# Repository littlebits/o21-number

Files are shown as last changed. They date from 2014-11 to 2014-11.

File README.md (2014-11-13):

Copyright 2014 littleBits Electronics.

littleBits, littleBits logo, Bits, cloudBit, are trademarks of littleBits Electronic Inc. 

littleBits Electronics, Inc. supports the Open Source Hardware Statement of Principles by making the circuit designs for its modules available pursuant to the CERN Hardware License, Version 1.2.

This is free software: you can redistribute it and/or modify it under the terms of the GNU General Public License as published by the Free Software Foundation, either version 3 of the License, or (at your option) any later version.

This software is distributed in the hope that it will be useful, but WITHOUT ANY WARRANTY; without even the implied warranty of MERCHANTABILITY or FITNESS FOR A PARTICULAR PURPOSE.  See the GNU General Public License at <http://www.gnu.org/licenses/> for more details.

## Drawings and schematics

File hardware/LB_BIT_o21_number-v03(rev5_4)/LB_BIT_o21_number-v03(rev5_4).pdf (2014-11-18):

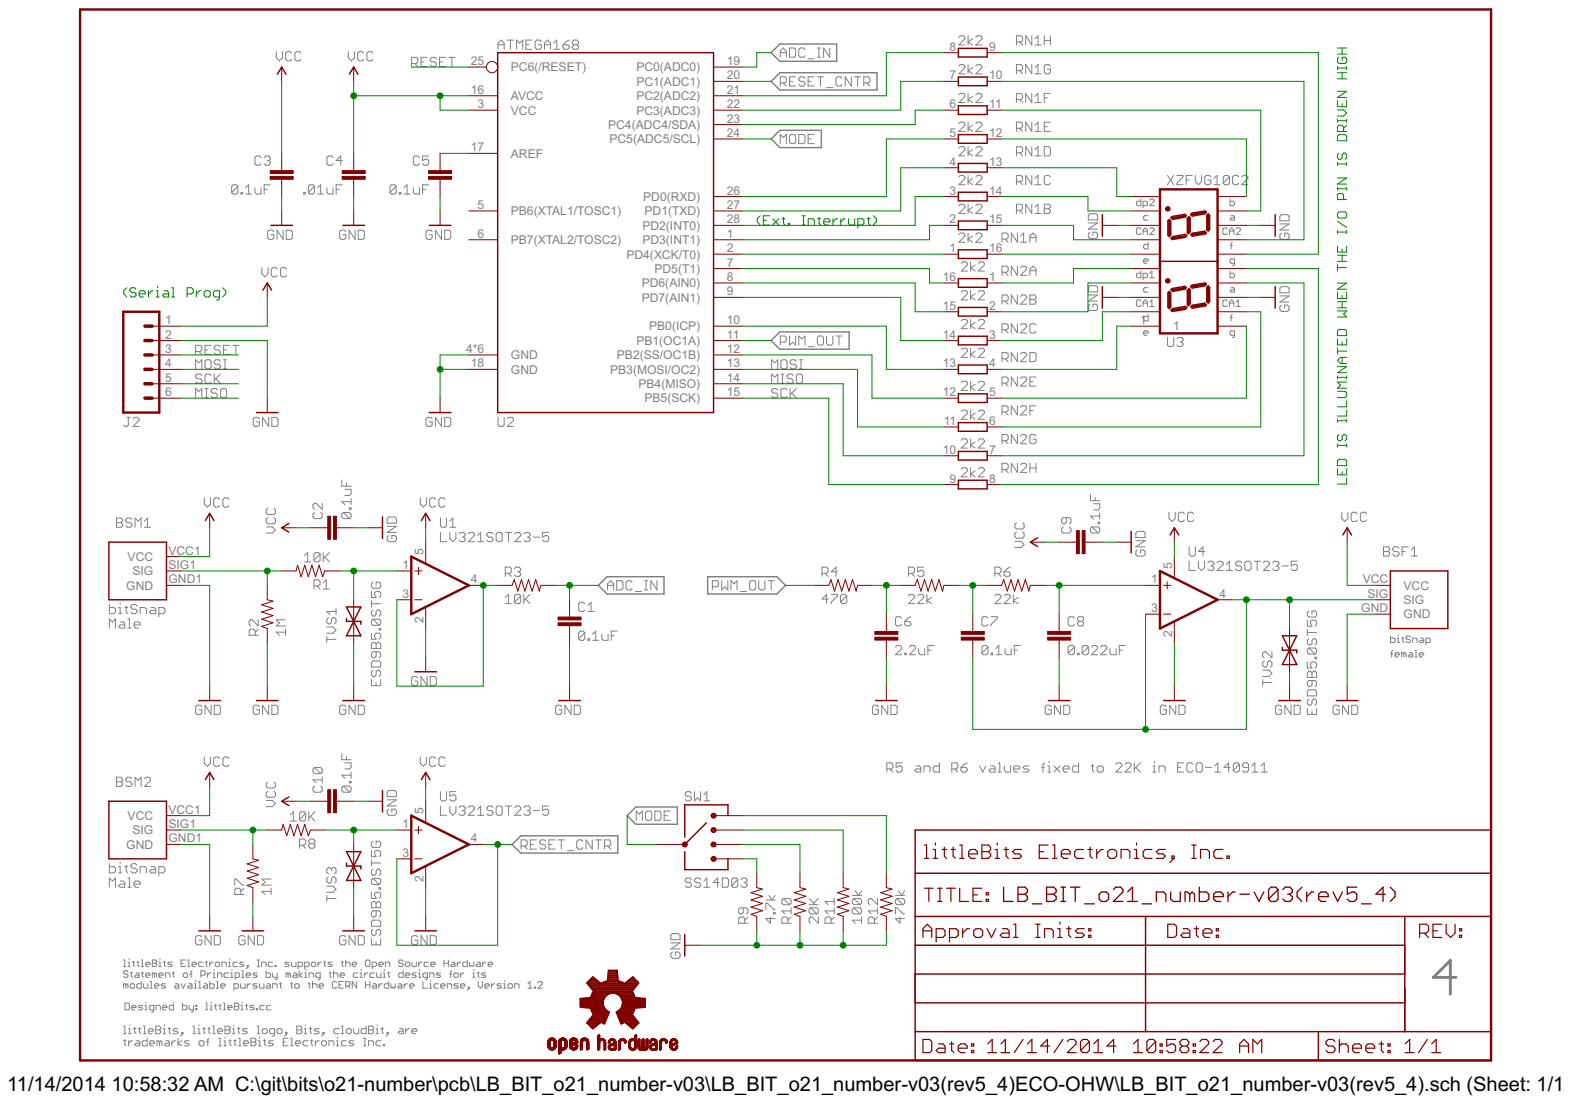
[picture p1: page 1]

11/14/2014 10:58:32 AM C:\git\bits\o21-number\pcb\LB_BIT_o21_number-v03\LB_BIT_o21_number-v03(rev5_4)ECO-OHW\LB_BIT_o21_number-v03(rev5_4).sch (Sheet: 1/1)

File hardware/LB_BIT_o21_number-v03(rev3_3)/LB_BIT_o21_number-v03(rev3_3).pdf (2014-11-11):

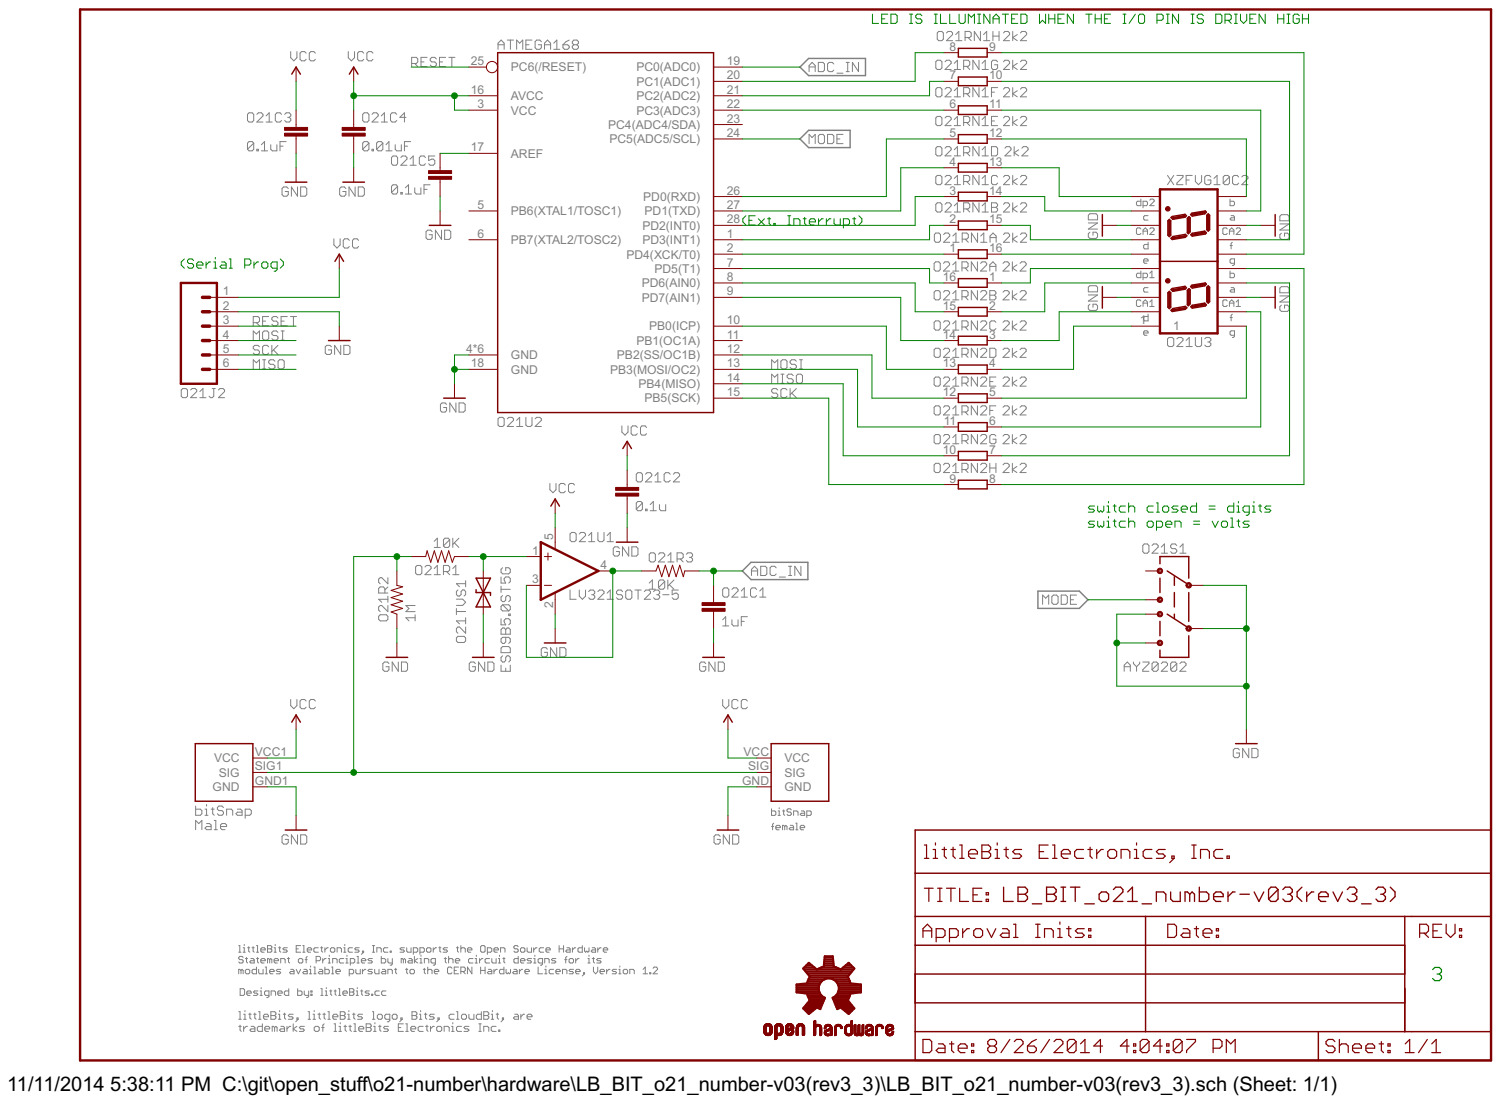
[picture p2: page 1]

11/11/2014 5:38:11 PM C:\git\open_stuff\o21-number\hardware\LB_BIT_o21_number-v03(rev3_3)\LB_BIT_o21_number-v03(rev3_3).sch (Sheet: 1/1)

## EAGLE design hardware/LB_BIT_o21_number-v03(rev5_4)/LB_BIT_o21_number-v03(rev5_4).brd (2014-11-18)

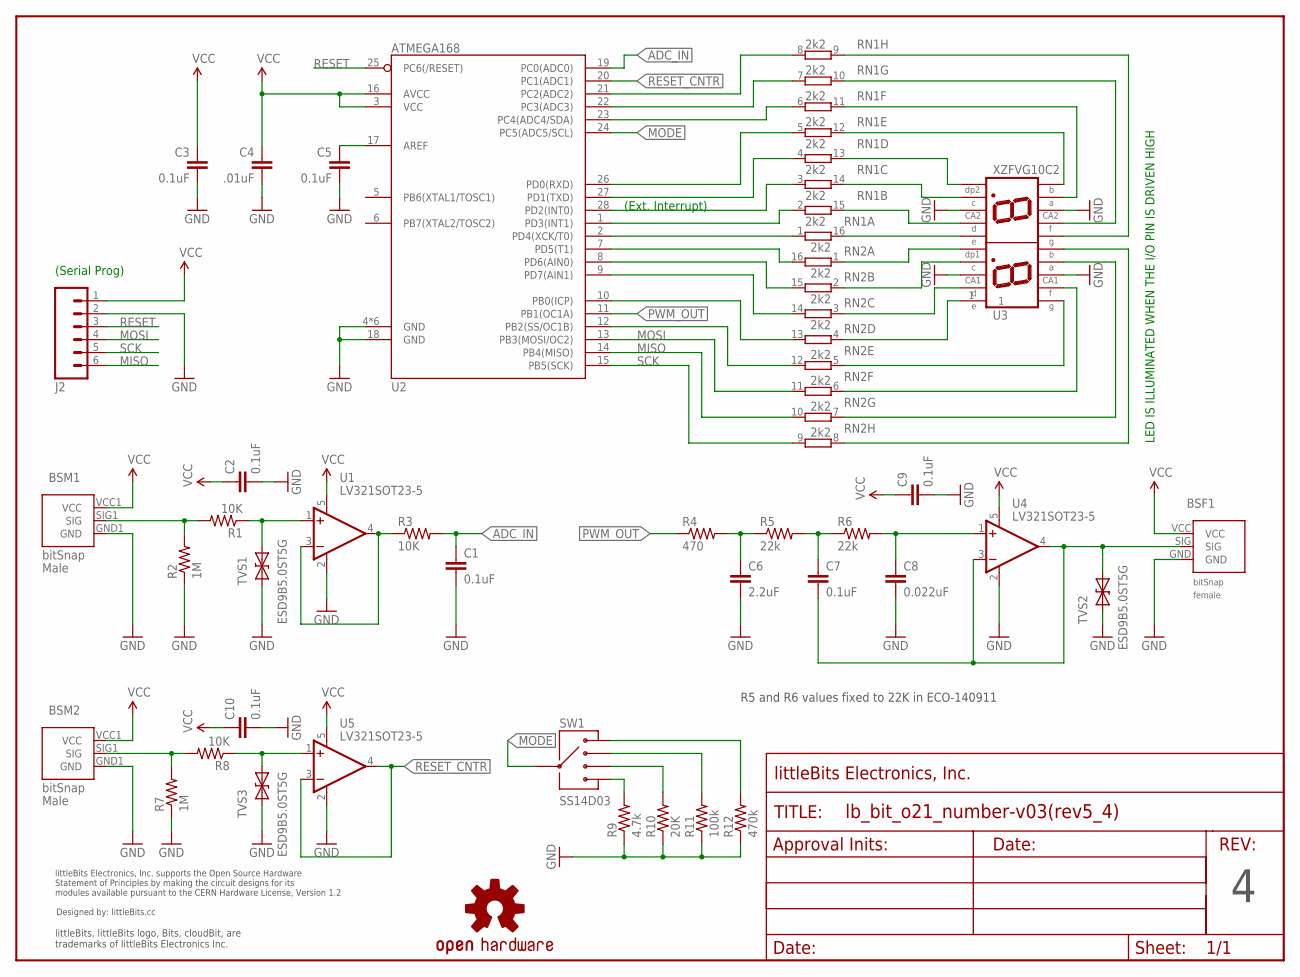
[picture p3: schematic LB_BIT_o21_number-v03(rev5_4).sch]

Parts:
BSF1: BITSNAP_V03_FEMALE
BSM1, BSM2: BITSNAP_V03_MALE
C1, C2, C3, C5, C7, C9, C10: 0.1uF; CAP-0603
C4: .01uF; CAP-0603
C6: 2.2uF; CAP-0603
C8: 0.022uF; CAP-0603
J2: HRD-60.1INCH_NO_SILKSCREEN; SIP6-SM-0.1IN-NOS.S.
R1, R3, R8: 10K; RES-0603
R2, R7: 1M; RES-0603
R4: 470; RES-0603
R5, R6: 22k; RES-0603
R9: 4.7k; RES-0603
R10: 20K; RES-0603
R11: 100k; RES-0603
R12: 470k; RES-0603
RN1, RN2: 2k2; EXB2HV
SW1: SS14D03; SWITCH-SLIDE-SP4T-SS14D03
TVS1, TVS2, TVS3: ESD9B5.0ST5G; SOD-923
U1, U4, U5: LV321SOT23-5; SOT23-5
U2: ATMEGA168; VQFN28
U3: XZFVG10C2; LED-DUAL7SEG-SM
U$1: FRAME-LETTER-OHWOHW; FABDWG01-OHW
U$2: OSHWCREDIT
U$27: OSHW-LOGOL; OSHW-LOGO-L

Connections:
ADC_IN: C1.1, R3.2, U2.19 (PC0(ADC0))
BIT_SIG: R3.1, U1.3 (-IN), U1.4 (OUT)
GND: BSF1.GND, BSM1.GND1 (GND), BSM2.GND1 (GND), C1.2, C2.2, C3.2, C4.2, C5.2, C6.2, C8.2, C9.2, C10.2, J2.2, R2.1, R7.1, R9.1, R10.1, R11.1, R12.1, TVS1.1 (A), TVS2.1 (A), TVS3.1 (A), U1.2 (V-), U2.4 (GND), U2.18 (GND), U2.TH (GND), U2.TH@1 (GND), U2.TH@2 (GND), U2.TH@3 (GND), U2.TH@4 (GND), U3.3, U3.8, U3.13, U3.18, U4.2 (V-), U5.2 (V-)
MISO: J2.6, RN2.10 (2), U2.14 (PB4(MISO))
MODE: SW1.COM, U2.24 (PC5(ADC5/SCL))
MOSI: J2.4, RN2.11 (2), U2.13 (PB3(MOSI/OC2))
unnamed: RN1.7 (1), U2.22 (PC3(ADC3))
unnamed: RN1.8 (1), U2.21 (PC2(ADC2))
unnamed: RN1.6 (1), U2.23 (PC4(ADC4/SDA))
unnamed: RN1.1, U2.2 (PD4(XCK/T0))
unnamed: RN1.2 (1), U2.1 (PD3(INT1))
unnamed: RN1.3 (1), U2.28 (PD2(INT0))
unnamed: RN1.4 (1), U2.27 (PD1(TXD))
unnamed: RN1.5 (1), U2.26 (PD0(RXD))
unnamed: RN2.16 (2), U2.7 (PD5(T1))
unnamed: RN2.15 (2), U2.8 (PD6(AIN0))
unnamed: RN2.14 (2), U2.9 (PD7(AIN1))
unnamed: RN2.13 (2), U2.10 (PB0(ICP))
unnamed: RN2.12 (2), U2.12 (PB2(SS/OC1B))
unnamed: C6.1, R4.2, R5.1
unnamed: C7.1, R5.2, R6.1
unnamed: RN1.16 (2), U3.6
unnamed: RN1.12 (2), U3.11
unnamed: RN1.11 (2), U3.12
unnamed: RN1.10 (2), U3.14
unnamed: RN1.9 (2), U3.15
unnamed: RN1.13 (2), U3.10
unnamed: RN1.15 (2), U3.7
unnamed: RN1.14 (2), U3.9
unnamed: C8.1, R6.2, U4.1 (+IN)
unnamed: RN2.1, U3.5
unnamed: RN2.2 (1), U3.4
unnamed: RN2.3 (1), U3.2
unnamed: RN2.4 (1), U3.1
unnamed: RN2.5 (1), U3.20
unnamed: RN2.6 (1), U3.19
unnamed: RN2.7 (1), U3.17
unnamed: RN2.8 (1), U3.16
unnamed: C5.1, U2.17 (AREF)
unnamed: R1.1, TVS1.2 (C), U1.1 (+IN)
unnamed: BSF1.SIG, C7.2, TVS2.2 (C), U4.3 (-IN), U4.4 (OUT)
unnamed: BSM2.SIG1 (SIG), R7.2, R8.2
unnamed: R12.2, SW1.1
unnamed: R8.1, TVS3.2 (C), U5.1 (+IN)
unnamed: R11.2, SW1.2
unnamed: R10.2, SW1.3
unnamed: R9.2, SW1.4
PWM_OUT: R4.1, U2.11 (PB1(OC1A))
RESET: J2.3, U2.25 (PC6(/RESET))
RESET_CNTR: U2.20 (PC1(ADC1)), U5.3 (-IN), U5.4 (OUT)
SCK: J2.5, RN2.9 (2), U2.15 (PB5(SCK))
SIG: BSM1.SIG1 (SIG), R1.2, R2.2
VCC: BSF1.VCC, BSM1.VCC1 (VCC), BSM2.VCC1 (VCC), C2.1, C3.1, C4.1, C9.1, C10.1, J2.1, U1.5 (V+), U2.3 (VCC), U2.16 (AVCC), U4.5 (V+), U5.5 (V+)

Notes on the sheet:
(Ext. Interrupt)
(Serial Prog)
LED IS ILLUMINATED WHEN THE I/O PIN IS DRIVEN HIGH
R5 and R6 values fixed to 22K in ECO-140911

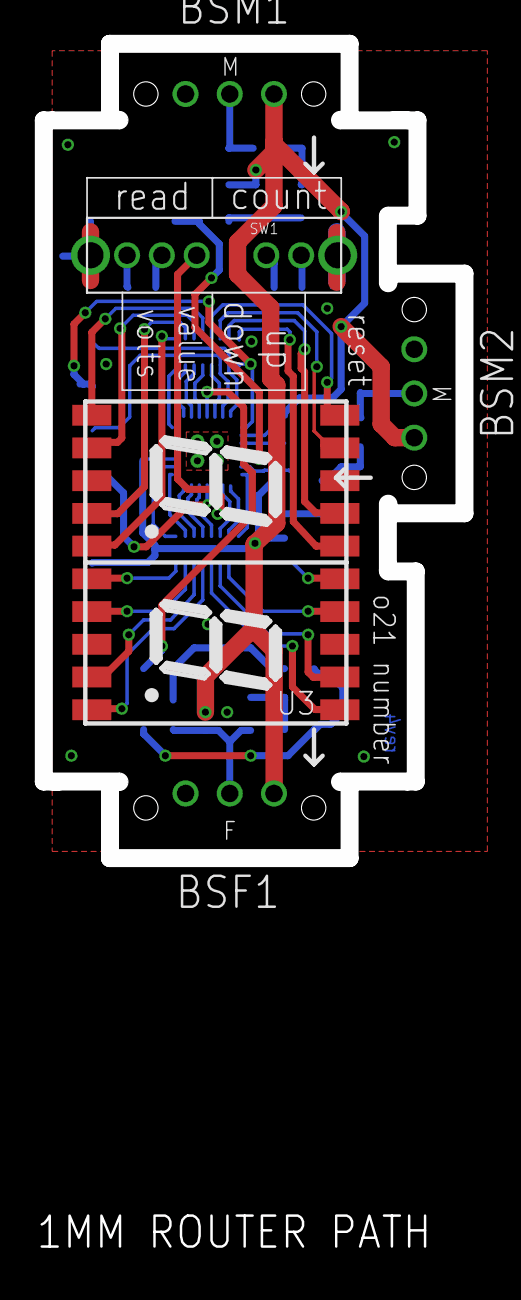
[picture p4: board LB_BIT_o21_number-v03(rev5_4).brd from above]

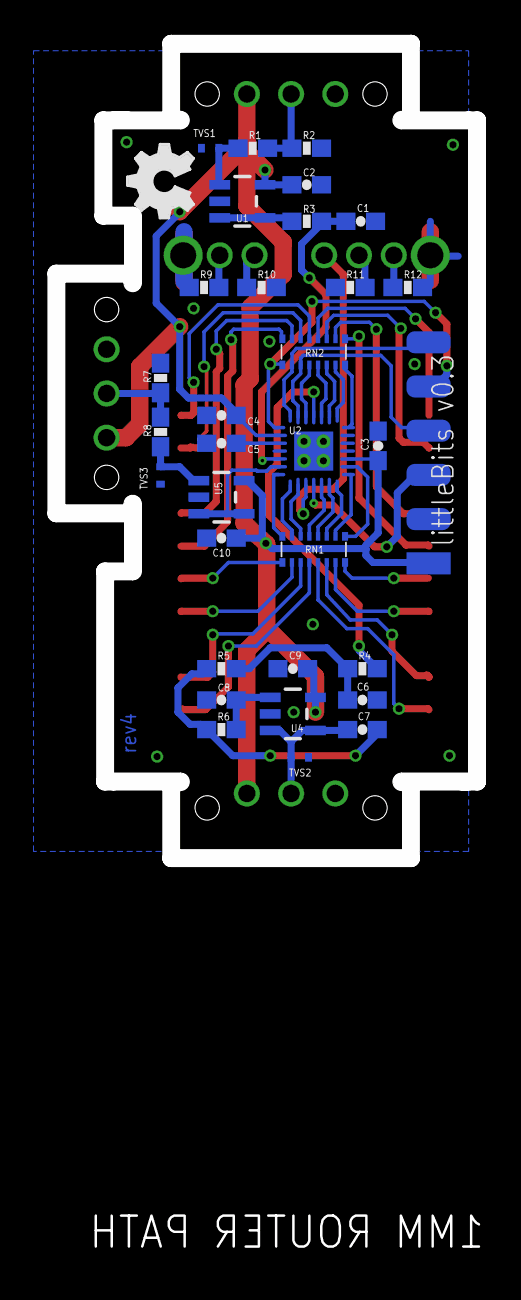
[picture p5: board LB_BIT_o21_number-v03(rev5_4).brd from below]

Board: 2 copper layers, 24.2 x 46.8 mm, 42 parts (32 on the bottom side), 53 nets.

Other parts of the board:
DRILEGEND: DRILEGEND
U$20: OSHW_FILLX150_NOTEXT

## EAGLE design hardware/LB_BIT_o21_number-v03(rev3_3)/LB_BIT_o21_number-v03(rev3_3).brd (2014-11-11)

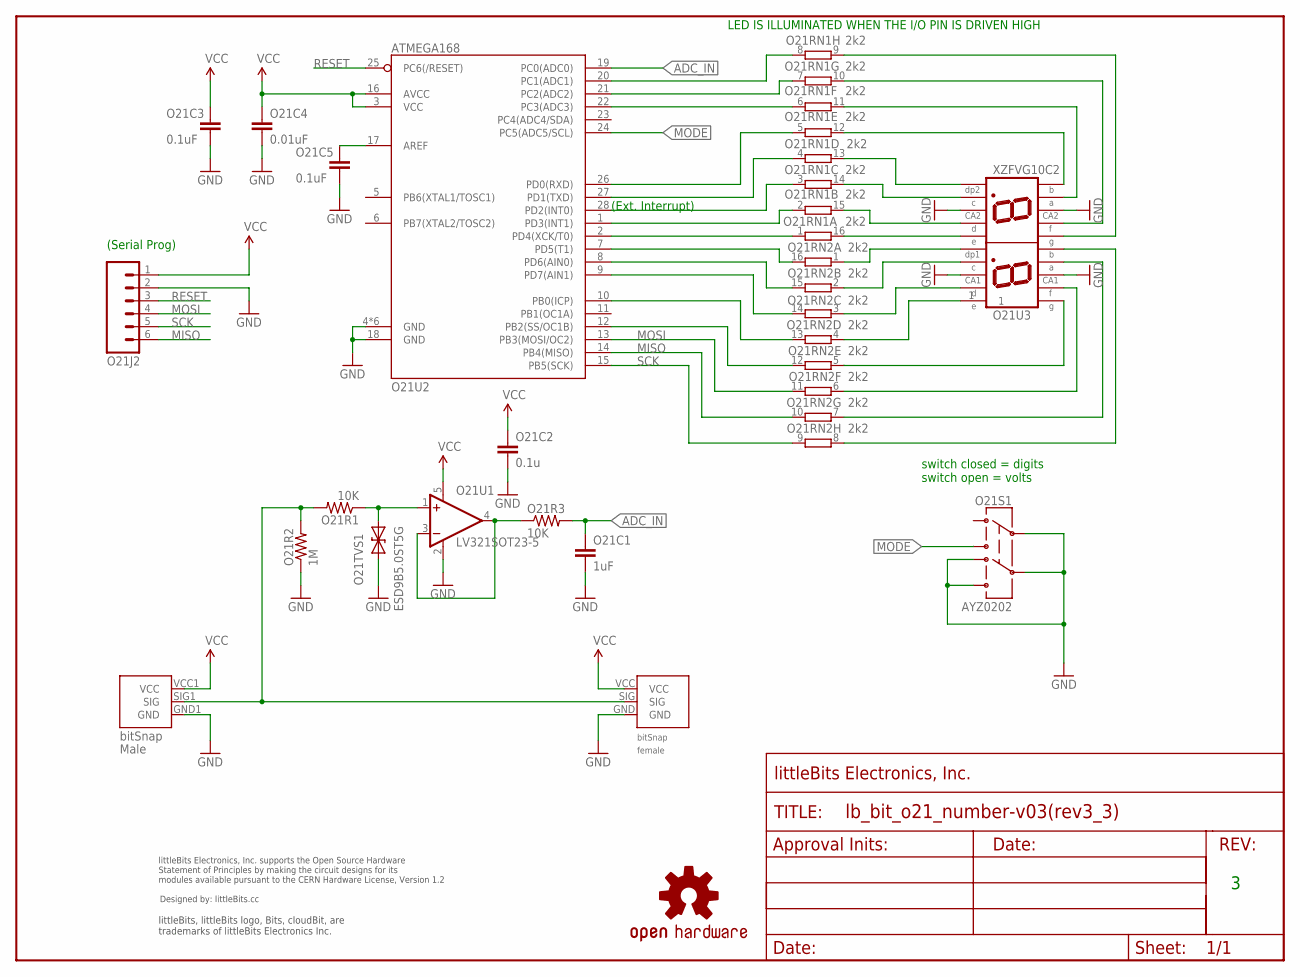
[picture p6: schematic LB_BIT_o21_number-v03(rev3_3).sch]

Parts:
O21BSF1: BITSNAP_V03_FEMALE
O21BSM1: BITSNAP_V03_MALE
O21C1: 1uF; CAP-0603
O21C2: 0.1u; CAP-0603
O21C3, O21C5: 0.1uF; CAP-0603
O21C4: 0.01uF; CAP-0603
O21J2: HRD-60.1INCH_NO_SILKSCREEN; SIP6-SM-0.1IN-NOS.S.
O21R1, O21R3: 10K; RES-0603
O21R2: 1M; RES-0603
O21RN1, O21RN2: 2k2; EXB2HV
O21S1: AYZ0202
O21TVS1: ESD9B5.0ST5G; SOD-923
O21U1: LV321SOT23-5; SOT23-5
O21U2: ATMEGA168; VQFN28
O21U3: XZFVG10C2; LED-DUAL7SEG-SM
U$7: OSHWCREDIT
U$16: FRAME-LETTER-OHWOHW; FABDWG01-OHW
U$27: OSHW-LOGOL; OSHW-LOGO-L

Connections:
ADC_IN: O21C1.1, O21R3.2, O21U2.19 (PC0(ADC0))
BIT_SIG: O21R3.1, O21U1.3 (-IN), O21U1.4 (OUT)
GND: O21BSF1.GND, O21BSM1.GND1 (GND), O21C1.2, O21C2.2, O21C3.2, O21C4.2, O21C5.2, O21J2.2, O21R2.1, O21S1.2, O21S1.4, O21S1.5, O21S1.6, O21TVS1.1 (A), O21U1.2 (V-), O21U2.4 (GND), O21U2.18 (GND), O21U2.TH (GND), O21U2.TH@1 (GND), O21U2.TH@2 (GND), O21U2.TH@3 (GND), O21U2.TH@4 (GND), O21U3.3, O21U3.8, O21U3.13, O21U3.18
MISO: O21J2.6, O21RN2.10 (2), O21U2.14 (PB4(MISO))
MODE: O21S1.3, O21U2.24 (PC5(ADC5/SCL))
MOSI: O21J2.4, O21RN2.11 (2), O21U2.13 (PB3(MOSI/OC2))
unnamed: O21RN1.7 (1), O21U2.21 (PC2(ADC2))
unnamed: O21RN1.8 (1), O21U2.20 (PC1(ADC1))
unnamed: O21RN1.6 (1), O21U2.22 (PC3(ADC3))
unnamed: O21RN1.1, O21U2.2 (PD4(XCK/T0))
unnamed: O21RN1.2 (1), O21U2.1 (PD3(INT1))
unnamed: O21RN1.3 (1), O21U2.28 (PD2(INT0))
unnamed: O21RN1.4 (1), O21U2.27 (PD1(TXD))
unnamed: O21RN1.5 (1), O21U2.26 (PD0(RXD))
unnamed: O21RN2.16 (2), O21U2.7 (PD5(T1))
unnamed: O21RN2.15 (2), O21U2.8 (PD6(AIN0))
unnamed: O21RN2.14 (2), O21U2.9 (PD7(AIN1))
unnamed: O21RN2.13 (2), O21U2.10 (PB0(ICP))
unnamed: O21RN2.12 (2), O21U2.12 (PB2(SS/OC1B))
unnamed: O21RN1.16 (2), O21U3.6
unnamed: O21RN1.12 (2), O21U3.11
unnamed: O21RN1.11 (2), O21U3.12
unnamed: O21RN1.10 (2), O21U3.14
unnamed: O21RN1.9 (2), O21U3.15
unnamed: O21RN1.13 (2), O21U3.10
unnamed: O21RN1.15 (2), O21U3.7
unnamed: O21RN1.14 (2), O21U3.9
unnamed: O21RN2.1, O21U3.5
unnamed: O21RN2.2 (1), O21U3.4
unnamed: O21RN2.3 (1), O21U3.2
unnamed: O21RN2.4 (1), O21U3.1
unnamed: O21RN2.5 (1), O21U3.20
unnamed: O21RN2.6 (1), O21U3.19
unnamed: O21RN2.7 (1), O21U3.17
unnamed: O21RN2.8 (1), O21U3.16
unnamed: O21C5.1, O21U2.17 (AREF)
unnamed: O21R1.1, O21TVS1.2 (C), O21U1.1 (+IN)
RESET: O21J2.3, O21U2.25 (PC6(/RESET))
SCK: O21J2.5, O21RN2.9 (2), O21U2.15 (PB5(SCK))
SIG: O21BSF1.SIG, O21BSM1.SIG1 (SIG), O21R1.2, O21R2.2
VCC: O21BSF1.VCC, O21BSM1.VCC1 (VCC), O21C2.1, O21C3.1, O21C4.1, O21J2.1, O21U1.5 (V+), O21U2.3 (VCC), O21U2.16 (AVCC)

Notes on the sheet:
(Ext. Interrupt)
(Serial Prog)
LED IS ILLUMINATED WHEN THE I/O PIN IS DRIVEN HIGH
switch closed = digits switch open = volts

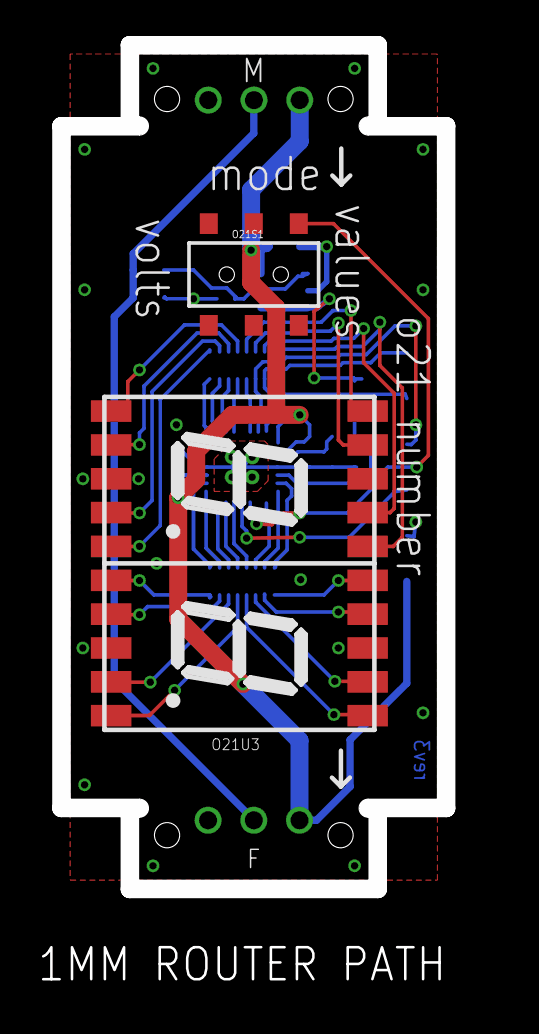
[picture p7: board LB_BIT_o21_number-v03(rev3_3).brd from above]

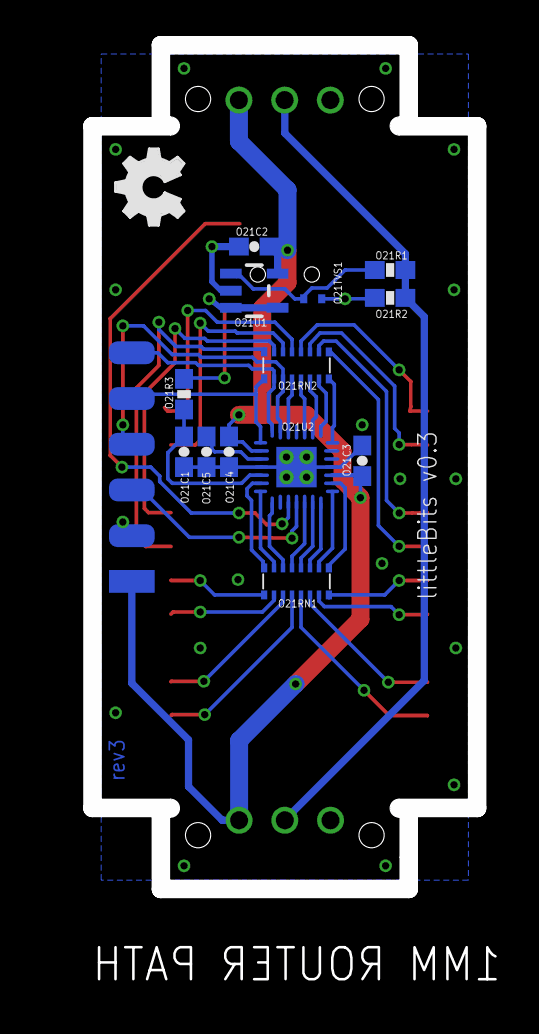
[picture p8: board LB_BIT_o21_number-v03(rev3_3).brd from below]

Board: 2 copper layers, 21.4 x 46.9 mm, 22 parts (14 on the bottom side), 41 nets.

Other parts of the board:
U$20: OSHW_FILLX150_NOTEXT

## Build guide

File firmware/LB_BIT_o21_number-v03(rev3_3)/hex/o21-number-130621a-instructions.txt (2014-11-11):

Programming Instructions

Step 1) Flash the micro controller with the accompanying .hex file.

Step 2) Set the fuses on the micro controller. Use the following fuse settings:

		EXTENDED:	0xF9
		HIGH:		0xCD
		LOW:		0x62

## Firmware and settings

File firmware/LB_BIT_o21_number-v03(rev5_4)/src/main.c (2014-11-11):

/*
*	main.c
*	uC = ATMega168-PA
*	SysClk = 1MHz (originating from internal 8 MHz RC oscillator and 1/8 prescalar)
*	Created: 5/27/2014 11:11:43 AM
*	Authors: littleBits Electronics, Inc.
*			MJ, Rory, Kristin
*
* Copyright 2014 littleBits Electronics
*
* This file is part of o21-number.
*
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
* This file incorporates work covered by the following copyright and
* permission notice:
*
*	Copyright 2013
*	source: http://www.dsprelated.com/showcode/304.php
*	
*	The code is released under Creative Commons Attribution 3.0. See the license
* 	at <https://creativecommons.org/licenses/by/3.0/us/legalcode> for more details.
*/


#include "o21-number.h"
#include "led_display.h"
#include "pwm_lookup.h"


// FUNCTION PROTOTYPES
static inline int16_t dsp_ema_i16(int16_t in, int16_t average, uint8_t alpha);	// First-order IIR LPF on incoming ADC signal
static inline void calc_number(struct display_data *display_values);			// Compute the outgoing display data in VALUES mode
static inline void calc_voltage(struct display_data *display_values);			// Compute the outgoing display data in VOLTS mode
static inline void output_display(struct display_data *display_values);			// Send the computed data out to the LED SSD for VALUES or VOLTS modes
static inline void output_display_counter(uint8_t value);						// Send the computed data out to the LED SSD for UP or DOWN modes

void reset_counter(uint8_t);		// Reset the counter value in UP or DOWN modes to the default values
void initialize_display();			// Initialize the LED SSD in UP or DOWN modes
void setup();						// Initialize WDT, LED SSD, pins, and interrupts


int main(void)
{

	setup();		// Initialize everything

	while(1)
	{
				
		// DSP for incoming ADC samples
		// We're using a 1-pole anti-aliasing LPF where Fc = 16 Hz
		//if( (state = !ready_for_adc_sample) )
		if (!ready_for_adc_sample)
		{
			sample_out_int16 = dsp_ema_i16(sample_in_int16, sample_out_int16, DSP_EMA_I16_ALPHA(0.01));		// LPF with 1st order exponential moving average IIR filter
			ready_for_adc_sample = 1;					// Set this flag HIGH again so that the ADC can take in a new sample in its next ISR
		}
		
		// The following 3 operations will execute one at a time at a rate of 333 Hz (rate depends on timer2's ISR)
		if (!operation_complete)
		{
			switch(state)
			{
				// case: READ MODE SWITCH
				case 0:
				
				if (mode_in <= 300)
				{
					switch_mode = UP;
					update_pwm = 1;
				}
				else if (mode_in > 300 && mode_in <= 600){
					switch_mode = DOWN;
					update_pwm = 1;
				}
				else if (mode_in > 600 && mode_in <= 850)
				{
					switch_mode = VALUES;
				}
				else if(mode_in > 850 && mode_in <= 1023)
				{
					switch_mode = VOLTS;
				}
				
				break;
				
				// case: COMPUTE DATA IN VALUES AND VOLTS MODES
				case 1:
				filtered_sample = (sample_out_int16 + 0x8000) >> 8;			// get filtered sample, offset to 0-65535 range, and downscale to 8-bit range
				if (switch_mode == VALUES)
				{
					calc_number(&new_output);								// compute date for SSD
				}
				else if (switch_mode == VOLTS)
				{
					calc_voltage(&new_output);								// compute data for SSD
				}

				break;
				

				// case: OUTPUT DATA TO DISPLAY
				case 2:
				
				if(switch_mode == VALUES || switch_mode == VOLTS)
				{
					output_display(&new_output);						// output to SSD
				}
				else if (switch_mode == UP || switch_mode == DOWN)
				{
					output_display_counter(counter_value);				// output to SSD
				}
				
				break;
				

			} //end switch
			
			operation_complete = 1;			// Set this flag HIGH so that timer2's ISR will know to move us into next state
			
			
		} //end if op complete
		
		
		// On rising edge of reset bitsnap pin, reset the counter to default values
		reset_state = READ_RESET_BUTTON();
		if(reset_state && !last_reset_state)
		reset_counter(switch_mode);
		last_reset_state = reset_state;
		
		wdt_reset();
		
	} //end while
	
} //end main


void setup()
{
	MCUSR &= ~(WDRF << 1);				// Clear the watchdog system reset flag
	wdt_enable(WDTO_60MS);				// Enable the watchdog timer. We specify a max-out period of 60 mS
	wdt_reset();						// Reset the watchdog timer

	adc_init(8);						// Initialize ADC. Use clock frequency of 1/8 of sysclock (125kHz). ADC reading takes 13 cycles, so ADC sample rate is 9.615kHz.
	_delay_ms(10);

	init_pwm_1();						// initialize PWM output and timer 1
	init_timer2();						// Initialize timer 2 to cycle through 3 states
	
	ENABLE_PCINT1();					// Enable the PCINT1
	INIT_PCINT1();						// Initialize PCINT1 trigger on PC0
	
	INIT_SWITCH();						// Initialize the mode switch pin
	INIT_RESET_BUTTON();				// Initialize the reset bitsnap signal pin
	INIT_INPUT_PULSE();					// Initialize the input bitsnap signal pin
	_delay_ms(1);
	
	init_led_outputs();					// Initialize 7 segment display
	initialize_display();				// Initialize display for counter mode

	wdt_reset();						// Reset WDT
}



ISR(PCINT1_vect)
{
	
	// On rising edge on input bitsnap pin, increment or decrement counter value and update pwm for output bitsnap
	// If there is a pulse on the input bitsnap
	if(READ_INPUT_PULSE())
	{
		switch(switch_mode)
		{
			case UP:
			// if we haven't hit our lower boundary
			if(counter_value < DOWN_DEFAULT)
			{
				counter_value++;	// increment
				update_pwm = 1;		// set flag to update PWM output
			}
			break;
			
			case DOWN:
			// if we haven't hit our upper boundary
			if(counter_value > UP_DEFAULT)
			{
				counter_value--;	// decrement
				update_pwm = 1;		// set flag to update PWM output
			}
			break;
			
			default:
			break;
			
		}
		
	}

	
}

// Interrupt should fire at a rate of ~1kHz
ISR(TIMER1_COMPA_vect)
{
	if (switch_mode == VALUES || switch_mode == VOLTS)
	{
		OUTPUT_BITSNAP = sig_in;
	}
	else if (switch_mode == UP || switch_mode == DOWN)
	{
		if(update_pwm)
		{
			OUTPUT_BITSNAP = pwm_lookup[counter_value];	//set output bitsnap pin to the scaled PWM output
			update_pwm = 0;								// clear the flag to update the PWM output
		}
	}

	
}


// Interrupt should fire at a rate of ~1kHz
ISR (TIMER2_COMPA_vect)
{
	mode_in = adc_read(5);			// read adc from switch mode pin

	if(operation_complete)
	{
		state++;
		state = state%3;
		operation_complete = 0;
	}
}


// This interrupt routine will be called every time that the ADC executes a new reading.
ISR(ADC_vect)
{
	
	if (switch_mode == VALUES || switch_mode == VOLTS)
	{
		// if we're ready to take in another ADC sample
		if(ready_for_adc_sample)
		{
			sig_in = adc_read(0);						// read adc on input bitsnap pin
			sample_in_int16 = (sig_in - 0x200) << 6;	// move reading to range of -512 to 512, upscale into 16-bit range
			ready_for_adc_sample = 0;					// clear flag so DSP can happen
		}
	}

}



// This is my modified version of original source code from: http://www.dsprelated.com/showcode/304.php
// This is a first order IIR lowpass filter, called an Exponential Moving Average filter.
// Decreasing the value of alpha lowers the cutoff frequency of the filter
int16_t dsp_ema_i16(int16_t in, int16_t average, uint8_t alpha)
{
	int32_t tmp0; // calcs must be done in 32-bit math to avoid overflow
	tmp0 = (int32_t)in * (alpha) + (int64_t)average * (256 - alpha);
	return (int16_t)((tmp0 + 128) / 256); // scale back to 32-bit (with rounding)
}

// Output all of the calculated values to the seven segment LED display:
static inline void output_display(struct display_data *display_values)
{
	
	display_left[display_values->left_digit]();
	display_right[display_values->right_digit]();
	display_decimal(display_values->decimal_point);
}

// Output counter mode values to LED SSD display:
static inline void output_display_counter(uint8_t value)
{
	uint8_t tens = value / 10;		// determine the most significant digit
	uint8_t ones = value % 10;		// determine the least significant digit
	
	display_left[tens]();			// put the MSD on the display
	display_right[ones]();			// put the LSD on the display
}


static inline void calc_number(struct display_data *display_values)
{
	
	if(filtered_sample > 249)
	filtered_sample = 249;
	
	// First let's calculate the 10's digit:
	// At this point the signal now ranges from 0-255.
	// We divide this into 10 sections (each with a difference of 26)
	// So tens_val will range from 0 to 9:
	uint16_t temp_left = filtered_sample/25;
	
	// Put this in here as a safety-guard to be sure we never try to access an address space beyond the limits of arrays
	if(temp_left > 9)
	temp_left = 9;
	
	// And finally pass these values on to our struct that holds data to be displayed:
	display_values->left_digit = temp_left;
	
	// Now to calculate the ones digit:
	// First we remove the largest multiple of 25 from the variable.
	// After this operation, remainder will range from 0 to 24:
	// We would want to divide 24 by 2.4 to get 10 divisions, but instead we shift both those operands up 8 bits:
	// So (24/10) << 8 = 6144/10 = 614... Divide by this value to get results ranging from 0-9...
	// This is fixed point arithmetic to avoid floating point computations
	
	uint16_t remainder = (filtered_sample%25) << 8;
	uint8_t ones_val = remainder/614;
	
	// Set any excessively high values to 9 (this operation will introduce a slight yet negligible inaccuracy to our display)
	if(ones_val > 9)
	ones_val = 9;
	
	// Pass on the computed ones value
	display_values->right_digit = ones_val;
	
	// Finally, make sure that the decimal point is turned off
	display_values->decimal_point = OFF;
	
}


// Recall for voltage mode, a shift of 5 bits (out of 256) in ADC readings corresponds to a change of 0.1 V (which should cause a display change)
static inline void calc_voltage(struct display_data *display_values)
{
	// Set up this new variable to hold our adc readings for these calculations
	// Apply an offset of two bits just for accuracy...
	// uint16_t temp_adc = filtered_sample + 1;
	
	uint16_t temp_adc = filtered_sample + 2;
	
	// At this point the signal now ranges from 0-255.
	// First let's calculate the 1's digit in voltage:
	// We divide the adc reading (ranging from 0-255) by 51.
	// After this operation, ones_digit will range from 0 to 5.
	uint8_t ones_digit = temp_adc/51;
	
	// If the value rises above 5, then cap it
	if (ones_digit > 5)
	ones_digit = 5;
	
	// Pass this computed value back out of the function to our struct that holds data to be displayed
	display_values->left_digit = ones_digit;
	
	// Now to calculate the decimal digit:
	// First we remove the largest multiple of 51 from the variable.
	// After this operation, remainder will vary from 0 to 50:
	uint8_t remainder = temp_adc%51;
	
	// This is a small scale-up patch used because our displays were outputting inaccurately high values in the 4V region.
	if( (ones_digit == 4) && (remainder > 4) )
	remainder -= 2;

	
	// This is a small scale-up patch used because our readings were outputting inaccurately low values in the lower half of the 1 - 1.5V region.
	//if( (ones_digit == 1) && ( remainder < 25) )
	//remainder += 2;
	
	// Now we divide this value by 5.
	// After this operation, dec_digit will range from 0 to 10
	uint8_t dec_digit = remainder/5;
	
	// Reduce any values of 10 to 9 (this operation will introduce a slight yet negligible inaccuracy to our display)
	if( dec_digit > 9)
	dec_digit = 9;
	
	// Now pass this computed value out of the function
	display_values->right_digit = dec_digit;

	display_values->decimal_point = ON;
}


void reset_counter(uint8_t sw_state)
{
	// if the bit is set to UP mode
	if(sw_state == UP)
	counter_value = UP_DEFAULT;
	// else the bit is set to DOWN mode
	else if (sw_state == DOWN)
	counter_value = DOWN_DEFAULT;
	
	update_pwm = 1;		// set the flag to update the PWM output
}

void initialize_display()
{
	mode_in = adc_read(5);		// read adc input from switch
	
	if (mode_in < 300)
	{
		switch_mode = UP;
		reset_counter(switch_mode);
		output_display_counter(counter_value);
	}
	else if (mode_in > 300 && mode_in < 600){
		switch_mode = DOWN;
		reset_counter(switch_mode);
		output_display_counter(counter_value);
	}
	else if(mode_in > 600 && mode_in < 850)
	{
		switch_mode = VALUES;
	}
	else if(mode_in > 850 && mode_in <1023)
	{
		switch_mode = VOLTS;
	}

}

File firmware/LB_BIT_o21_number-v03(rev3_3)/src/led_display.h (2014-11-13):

/*
 * led_display.h\
 *
 * Created: 5/22/2014 5:18:23 PM
 *
 * Copyright 2014 littleBits Electronics
 *
 * This file is part of o21-number.
 *
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
 * This file incorporates work covered by the following copyright and
 * permission notice:
 *
 *	Copyright 2013
 *	source: http://www.dsprelated.com/showcode/304.php
 *	
 *	The code is released under Creative Commons Attribution 3.0. See the license
 * 	at <https://creativecommons.org/licenses/by/3.0/us/legalcode> for more details.
 */ 


#ifndef LED_DISPLAY_H_
#define LED_DISPLAY_H_

#define LEFT_A (1 << PB4)
#define LEFT_B (1 << PB5)
#define LEFT_C (1 << PD6)
#define LEFT_D (1 << PD7)
#define LEFT_E (1 << PB0)
#define LEFT_F (1 << PB3)
#define LEFT_G (1 << PB2)

#define RIGHT_A (1 << PC4)
#define RIGHT_B (1 << PD0)
#define RIGHT_C (1 << PD2)
#define RIGHT_D (1 << PD3)
#define RIGHT_E (1 << PD4)
#define RIGHT_F (1 << PC3)
#define RIGHT_G (1 << PC2)

#define DECIMAL_PT_L (1 << PD5)
#define DECIMAL_PT_R (1 << PD1)


// This enumeration will be used in the display_decimal() function below:
enum decimal_point {OFF, ON};

// This function will control the pin that drives the decimal point of the LED display
inline void display_decimal(int decimal_status)
{
	if(decimal_status == ON)
	PORTD |= DECIMAL_PT_L;			// Turn the LED display for decimal point on
	else 						// else assume decimal_status == OFF, so:
	PORTD &= ~DECIMAL_PT_L;			// Turn the LED display for decimal point off
}

// This function specifies the behavior of the pins that drive the LED display.
// Setting a '1' in these ports designates the pins as outputs (as opposed to inputs or something else)

inline void init_led_outputs()
{
	DDRB |= LEFT_A|LEFT_B|LEFT_E|LEFT_F|LEFT_G;
	DDRC |= RIGHT_A|RIGHT_F|RIGHT_G;
	DDRD |= LEFT_C|LEFT_D|RIGHT_B|RIGHT_C|RIGHT_D|RIGHT_E|DECIMAL_PT_L|DECIMAL_PT_R;
}

///////////////////////////////////////////////////////////////////////////////////////////////////////////////////////////
///////////////////// The following functions control the pins that drive the LED display's left digit ////////////////////
///////////////////////////////////////////////////////////////////////////////////////////////////////////////////////////


void l_zero()
{
	PORTB |= LEFT_A|LEFT_B|LEFT_E|LEFT_F;
	PORTB &= ~LEFT_G;
	
	PORTD |= LEFT_C|LEFT_D;
}

void l_one()
{
	PORTB |= LEFT_B;
	PORTB &= ~(LEFT_A|LEFT_E|LEFT_F|LEFT_G);

	PORTD |= LEFT_C;
	PORTD &= ~LEFT_D;
}

void l_two()
{
	PORTB |= LEFT_A|LEFT_B|LEFT_E|LEFT_G;
	PORTB &= ~LEFT_F;

	PORTD |= LEFT_D;
	PORTD &= ~LEFT_C;
}

void l_three()
{
	PORTB |= LEFT_A|LEFT_B|LEFT_G;
	PORTB &= ~(LEFT_F|LEFT_E);

	PORTD |= LEFT_C|LEFT_D;
}

void l_four()
{
	PORTB |= LEFT_F|LEFT_B|LEFT_G;
	PORTB &= ~(LEFT_A|LEFT_E);

	PORTD |= LEFT_C;
	PORTD &= ~LEFT_D;
}

void l_five()
{
	PORTB |= LEFT_A|LEFT_F|LEFT_G;
	PORTB &= ~(LEFT_B|LEFT_E);

	PORTD |= LEFT_C|LEFT_D;
}

void l_six()
{
	PORTB |= LEFT_A|LEFT_E|LEFT_F|LEFT_G;
	PORTB &= ~LEFT_B;

	PORTD |= LEFT_C|LEFT_D;
}

void l_seven()
{
	PORTB |= LEFT_A|LEFT_B;
	PORTB &= ~(LEFT_E|LEFT_F|LEFT_G);

	PORTD |= LEFT_C;
	PORTD &= ~LEFT_D;
}

void l_eight()
{
	PORTB |= LEFT_A|LEFT_B|LEFT_E|LEFT_F|LEFT_G;

	PORTD |= LEFT_C|LEFT_D;
}

void l_nine()
{
	PORTB |= LEFT_A|LEFT_B|LEFT_E|LEFT_F|LEFT_G;
	PORTB &= ~LEFT_E;

	PORTD |= LEFT_C|LEFT_D;
}




////////////////////////////////////////////////////////////////////////////////////////////////////////////////////////////
///////////////////// The following functions control the pins that drive the LED display's right digit ////////////////////
////////////////////////////////////////////////////////////////////////////////////////////////////////////////////////////

void r_zero()
{
	PORTC |= RIGHT_A|RIGHT_F;
	PORTC &= ~RIGHT_G;

	PORTD |= RIGHT_B|RIGHT_C|RIGHT_D|RIGHT_E;
}

void r_one()
{
	PORTC &= ~(RIGHT_A|RIGHT_F|RIGHT_G);

	PORTD |= RIGHT_B|RIGHT_C;
	PORTD &= ~(RIGHT_D|RIGHT_E);
}

void r_two()
{
	PORTC |= RIGHT_A|RIGHT_G;
	PORTC &= ~RIGHT_F;

	PORTD |= RIGHT_B|RIGHT_D|RIGHT_E;
	PORTD &= ~RIGHT_C;
}

void r_three()
{
	PORTC |= RIGHT_A|RIGHT_G;
	PORTC &= ~RIGHT_F;

	PORTD |= RIGHT_B|RIGHT_D|RIGHT_C;
	PORTD &= ~RIGHT_E;
}

void r_four()
{
	PORTC |= RIGHT_G|RIGHT_F;
	PORTC &= ~RIGHT_A;

	PORTD |= RIGHT_B|RIGHT_C;
	PORTD &= ~(RIGHT_E|RIGHT_D);
}

void r_five()
{
	PORTC |= RIGHT_A|RIGHT_F|RIGHT_G;

	PORTD |= RIGHT_D|RIGHT_C;
	PORTD &= ~(RIGHT_B|RIGHT_E);
}

void r_six()
{
	PORTC |= RIGHT_A|RIGHT_F|RIGHT_G;

	PORTD |= RIGHT_C|RIGHT_D|RIGHT_E;
	PORTD &= ~RIGHT_B;
}

void r_seven()
{
	PORTC &= ~(RIGHT_F|RIGHT_G);
	PORTC |= RIGHT_A;

	PORTD |= RIGHT_C|RIGHT_B;
	PORTD &= ~(RIGHT_D|RIGHT_E);
}

void r_eight()
{
	PORTC |= RIGHT_A|RIGHT_F|RIGHT_G;

	PORTD |= RIGHT_B|RIGHT_C|RIGHT_D|RIGHT_E;
}

void r_nine()
{
	PORTC |= RIGHT_A|RIGHT_F|RIGHT_G;

	PORTD |= RIGHT_B|RIGHT_C|RIGHT_D;
	PORTD &= ~RIGHT_E;
}


///////////////////////////////////////////////////////////////////////////////////////////////////////////////////////////
///	These are arrays of pointers to functions. These arrays function like lookup tables for the left and			///
/// 	right display numbers. The functions that we point to control the GPIO pins that drive the LED displays		///
///////////////////////////////////////////////////////////////////////////////////////////////////////////////////////////

void (*display_left[10])(void) = {l_zero, l_one, l_two, l_three, l_four, l_five, l_six, l_seven, l_eight, l_nine};
void (*display_right[10])(void) = {r_zero, r_one, r_two, r_three, r_four, r_five, r_six, r_seven, r_eight, r_nine};





#endif /* LED_DISPLAY_H_ */

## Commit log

2014-11-11 First commit, added hardware and software files
    [LB_BIT_o21_number-v03(rev3_3).brd, LB_BIT_o21_number-v03(rev3_3).sch]
2014-11-18 Added firmware and hardware for new rev 5_4
    [LB_BIT_o21_number-v03(rev5_4).brd, LB_BIT_o21_number-v03(rev5_4).sch]
2015-02-21 Replaces src for 3_3 with correct version
    [main.c, o21-number.c, o21-number.h]

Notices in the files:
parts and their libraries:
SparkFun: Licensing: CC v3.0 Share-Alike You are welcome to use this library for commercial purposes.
